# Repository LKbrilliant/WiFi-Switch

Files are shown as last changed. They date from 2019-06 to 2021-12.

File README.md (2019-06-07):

# WiFi-Switch 
📡 **WiFi-Switch** is a wall outlet adapter which can be controlled through the home wierless network. It can turn On/Off any device which plugs into it. This project is based on the ESP8266-01 module. Independent static-ip addresses can be use when deploying several switches around the house.

Schematics:
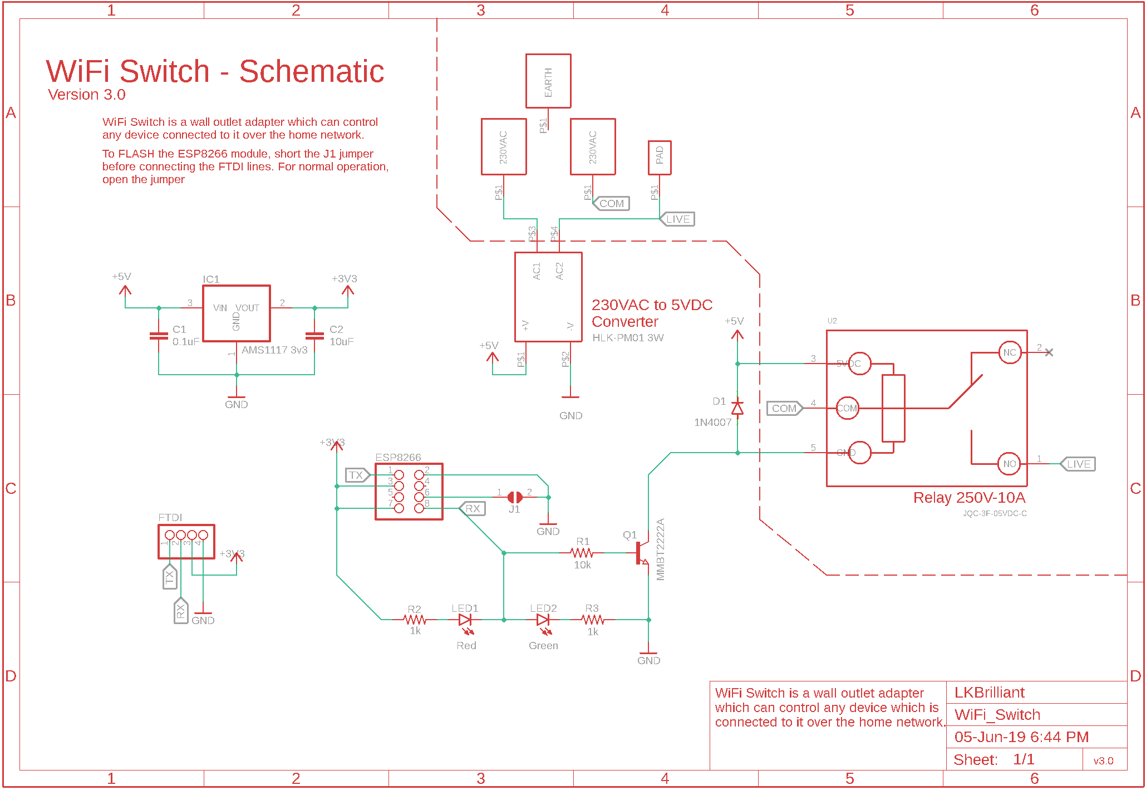
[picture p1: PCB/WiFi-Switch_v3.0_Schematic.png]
Schematic


PCB:
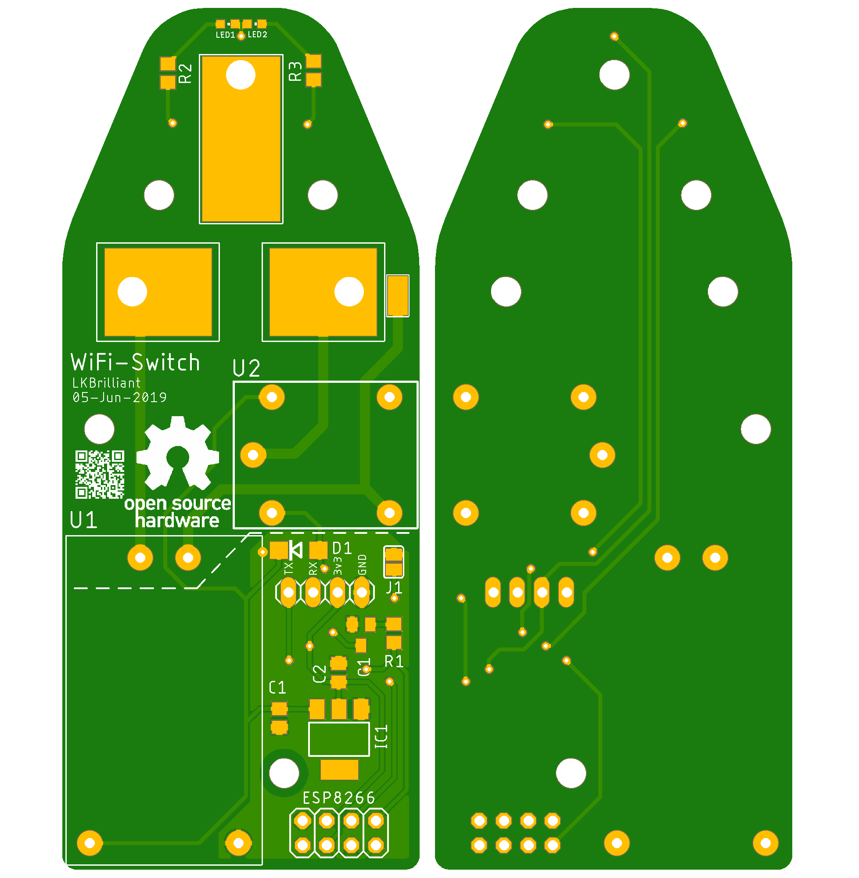
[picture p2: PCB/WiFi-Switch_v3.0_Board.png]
Board


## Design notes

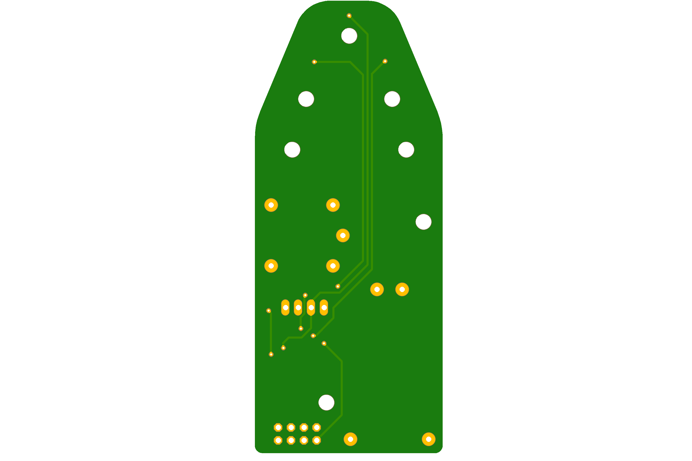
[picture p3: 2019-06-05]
PCB/WiFi-Switch_v3.0_Board_back.png

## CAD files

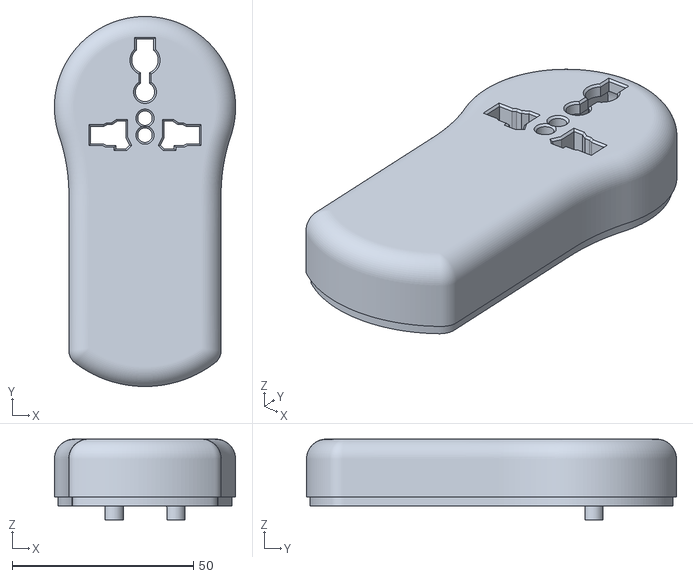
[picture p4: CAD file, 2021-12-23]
3D-models/Front.stl
50.0 x 102.1 x 22.3

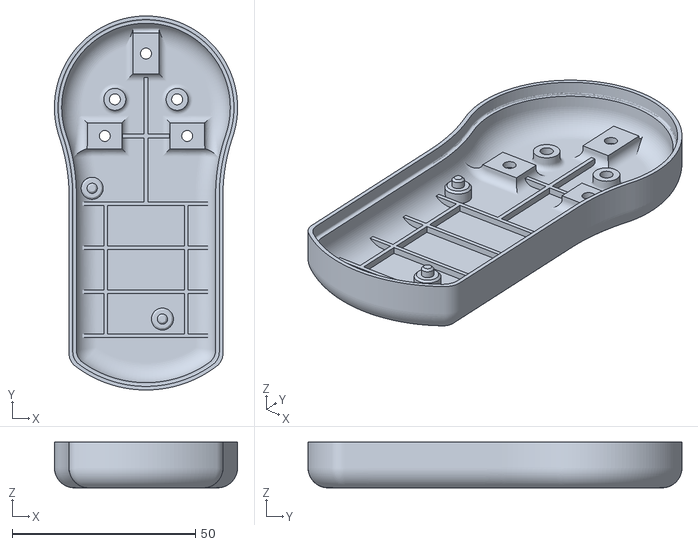
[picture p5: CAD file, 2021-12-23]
3D-models/Back.stl
50.0 x 102.1 x 12.5

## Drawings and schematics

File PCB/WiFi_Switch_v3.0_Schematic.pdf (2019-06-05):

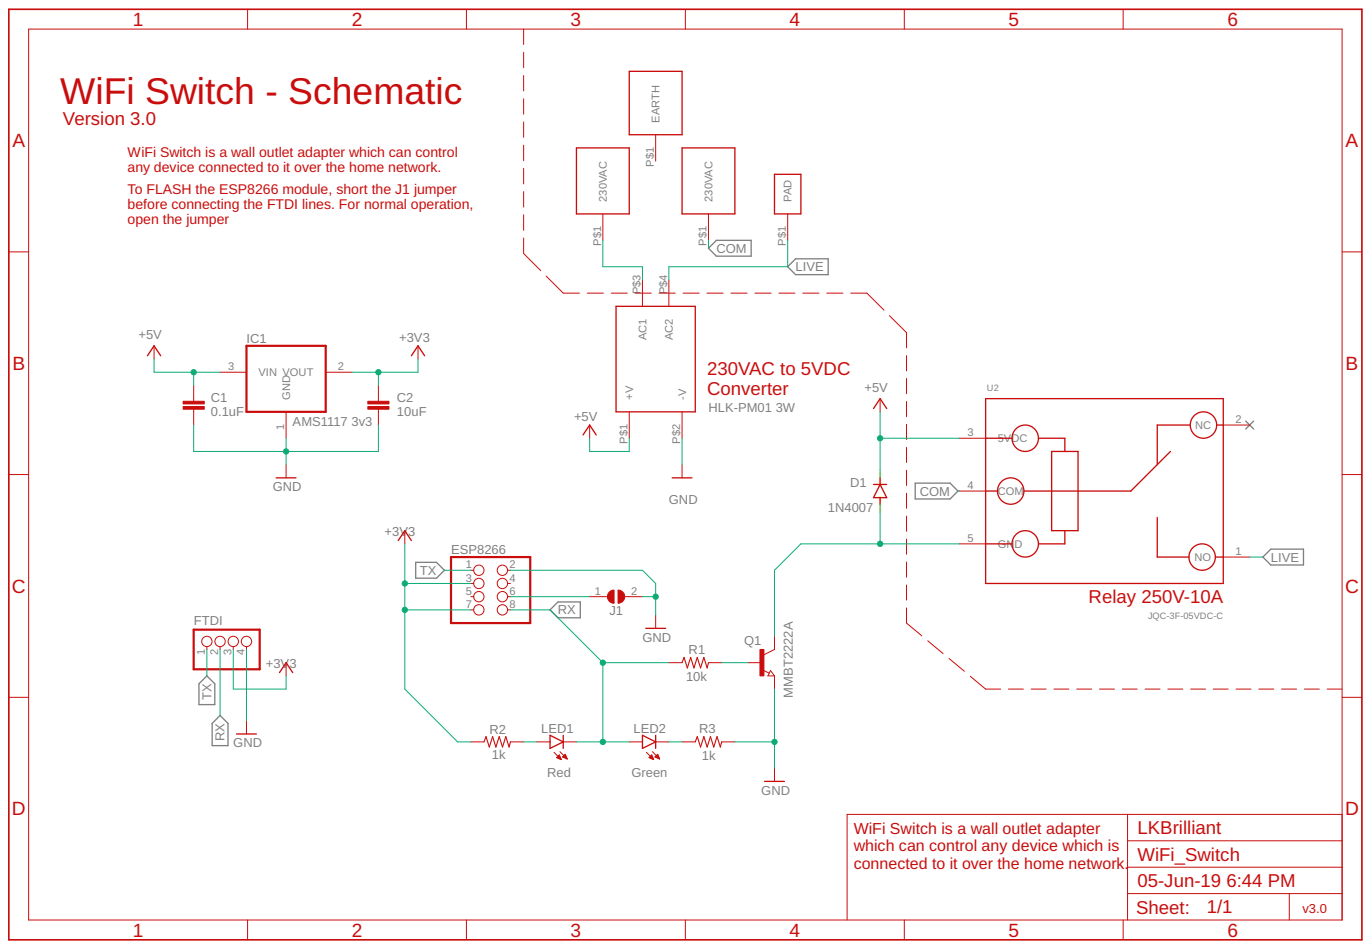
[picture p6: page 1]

WiFi Switch is a wall outlet adapter which can control any device connected to it over the home network. To FLASH the ESP8266 module, short the J1 jumper before connecting the FTDI lines. For normal operation, open the jumper

which can control any device which is
connected to it over the home network.

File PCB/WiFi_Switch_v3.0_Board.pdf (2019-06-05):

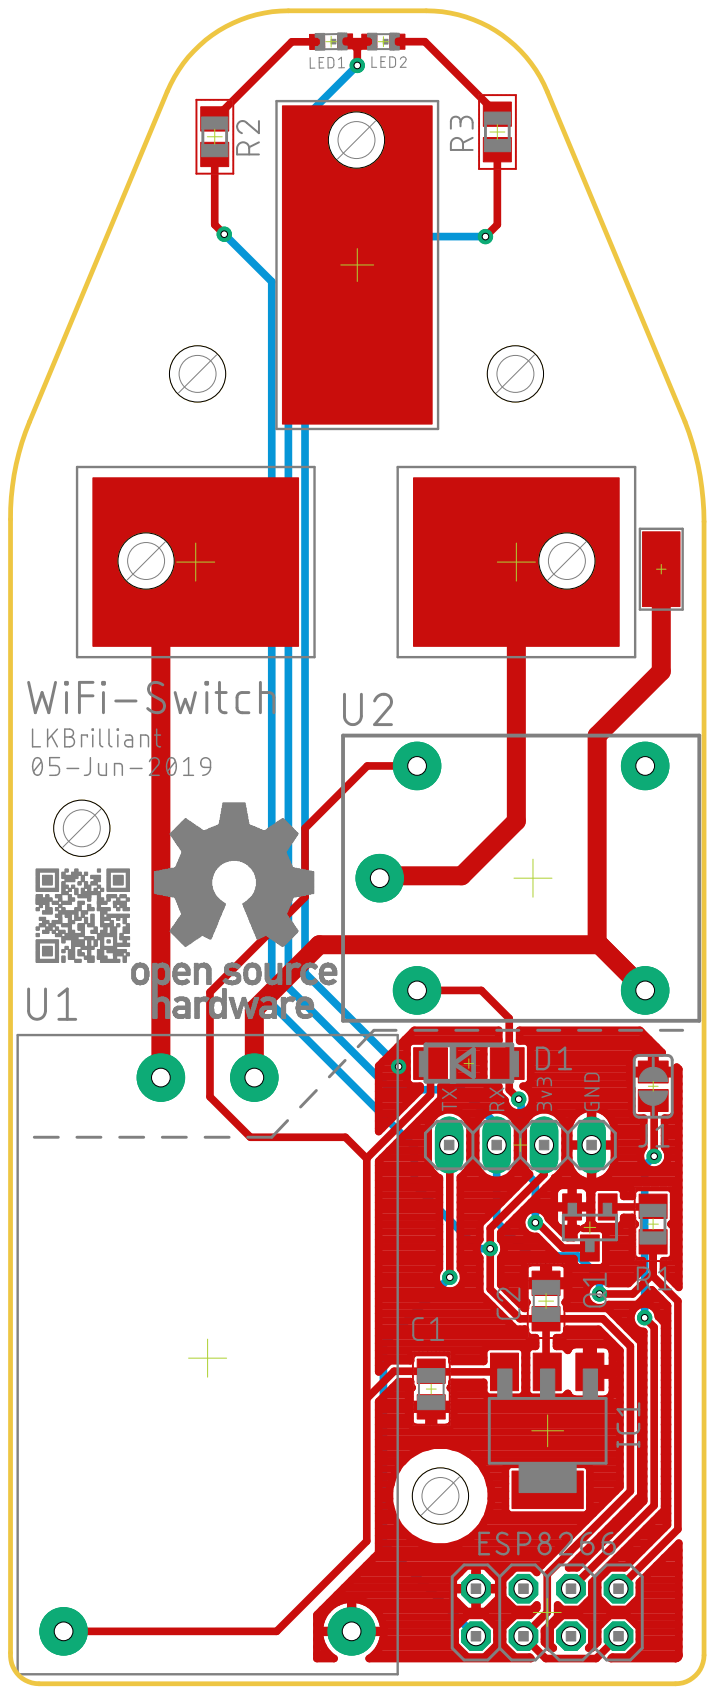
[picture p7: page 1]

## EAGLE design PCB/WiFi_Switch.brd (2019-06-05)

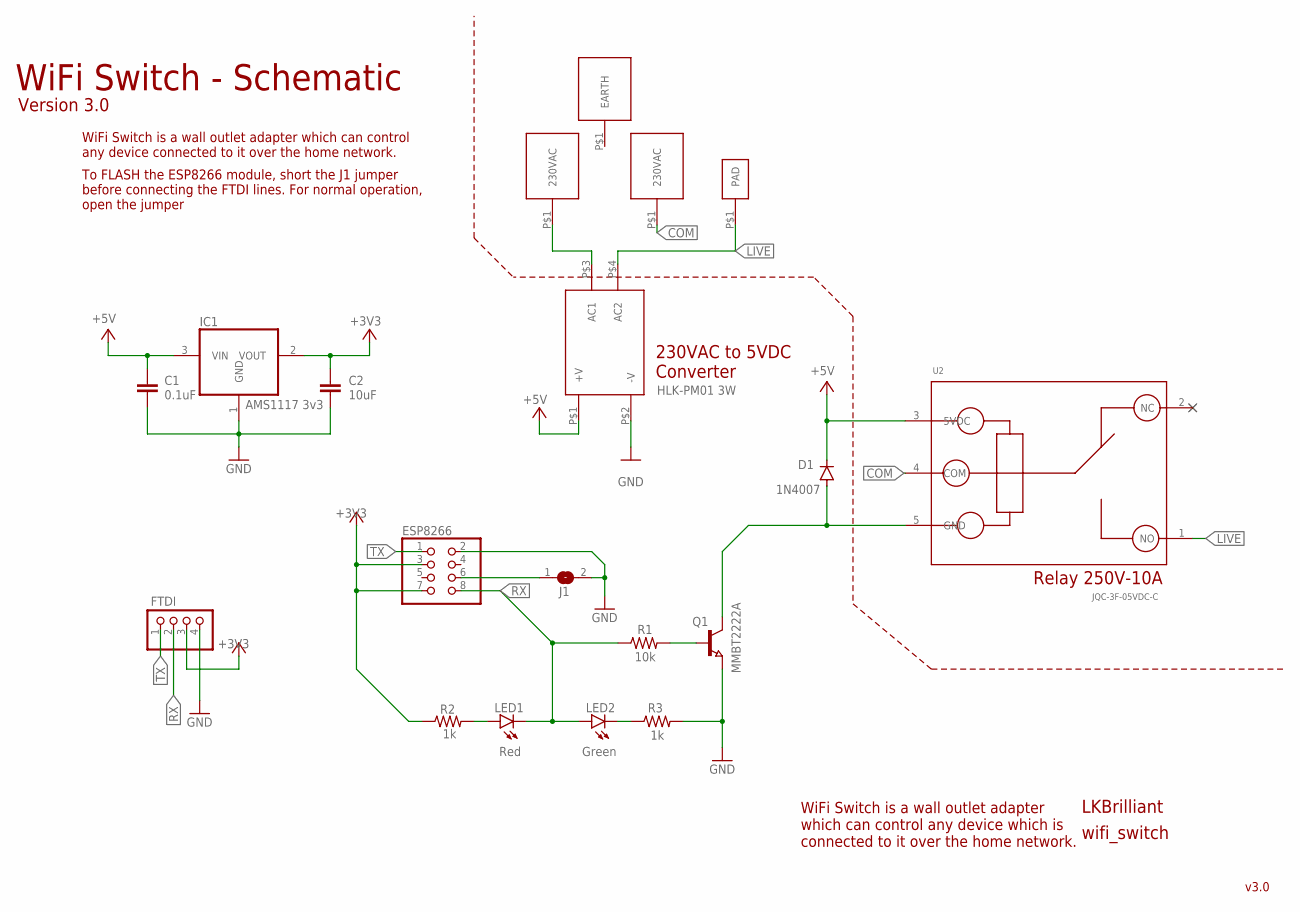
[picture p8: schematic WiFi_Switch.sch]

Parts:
C1: 0.1uF; C0805
C2: 10uF; C0805
D1: 1N4007; DO214AC
ESP8266: PINHD-2X4; 2X04
FTDI: PINHD-1X4; 1X04
IC1: AMS1117 3v3; SOT223
J1: SJ
L: 230VAC_PAD; 11X9_SMD_PAD
LED1: Red; CHIPLED_0603
LED2: Green; CHIPLED_0603
N: 230VAC_PAD; 11X9_SMD_PAD
Q1: MMBT2222A; SOT23
R1: 10k; R0805
R2, R3: 1k; R0805
U1: 230VAC/5VDC_CONVERTER; REG_BLOCK
U2: JQC-3F-05VDC-C; JQC-3F
U$4: EARTH_PAD; 17X8_PAD
U$5: EXT_PAD; 4X2_PAD

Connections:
+3V3: C2.1, ESP8266.3, ESP8266.7, FTDI.3, IC1.2 (VOUT), R2.1
+5V: C1.1, D1.C, IC1.3 (VIN), U1.P$1 (+V), U2.3 (5VDC)
COM: L.P$1, U2.4 (COM)
GND: C1.2, C2.2, ESP8266.2, FTDI.4, IC1.1 (GND), J1.2, Q1.2 (E), R3.2, U1.P$2 (-V)
LIVE: U1.P$4 (AC2), U2.1 (NO), U$5.P$1
unnamed: LED1.A, R2.2
unnamed: N.P$1, U1.P$3 (AC1)
unnamed: ESP8266.6, J1.1
unnamed: D1.A, Q1.3 (C), U2.5 (GND)
unnamed: LED2.C, R3.1
unnamed: Q1.1 (B), R1.2
RX: ESP8266.8, FTDI.2, LED1.C, LED2.A, R1.1
TX: ESP8266.1, FTDI.1

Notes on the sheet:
v3.0
LKBrilliant
WiFi Switch is a wall outlet adapter which can control any device which is connected to it over the home network.
230VAC to 5VDC Converter
HLK-PM01 3W
Relay 250V-10A
WiFi Switch - Schematic
Version 3.0
WiFi Switch is a wall outlet adapter which can control any device connected to it over the home network.
To FLASH the ESP8266 module, short the J1 jumper before connecting the FTDI lines. For normal operation, open the jumper

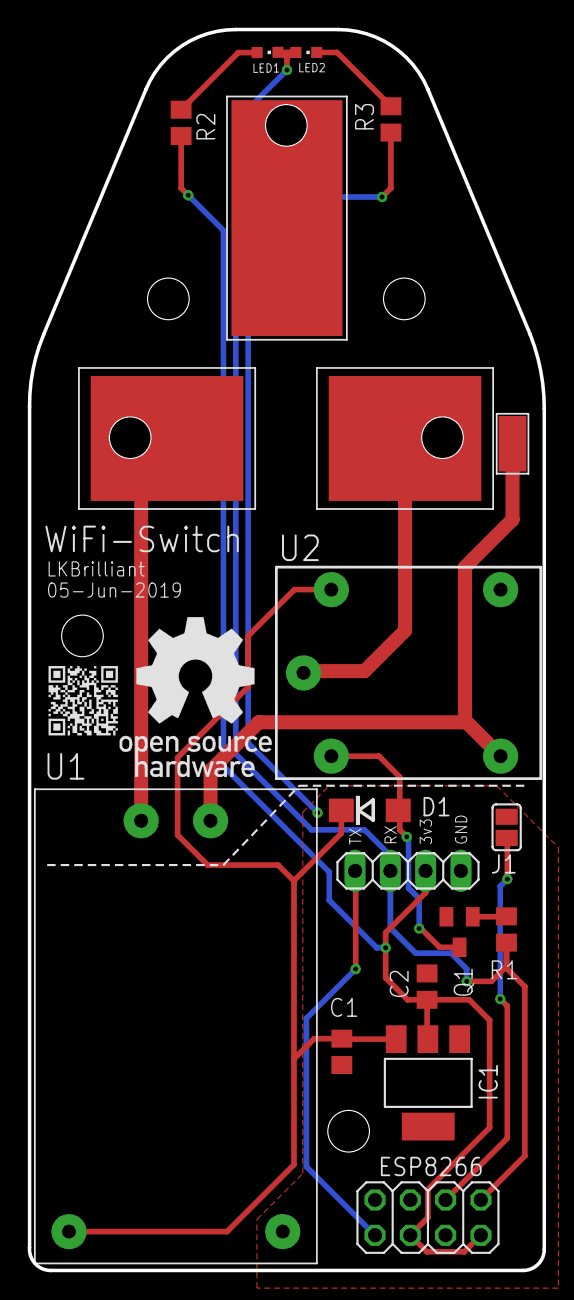
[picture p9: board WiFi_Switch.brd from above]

Board: 2 copper layers, 37.1 x 89.4 mm, 19 parts (0 on the bottom side), 13 nets.

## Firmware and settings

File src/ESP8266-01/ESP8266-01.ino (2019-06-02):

/*  
  Code by   :   Anuradha Gunawardhana
  date      :   02-Jun-2019
  version   :   1.0.020619

*/


#define relay 3   // relay is on GPIO 3 
#define led 1     //On board LED

#include <ESP8266WiFi.h>
#include <WiFiClient.h>
#include <ESP8266WebServer.h>

#include "index.h"                        // HTML webpage contents with javascripts

// Your WiFi credentials
const char* ssid = "YOUR_SSID";
const char* password = "YOUR_PASSWORD";

String current_relay_state = "0";  

ESP8266WebServer server(80);              //Server on port 80

IPAddress staticIP(192, 168, 1, 90);      // ESP static ip
IPAddress gateway(192, 168, 1, 1);        // IP Address of WiFi Router (Gateway)
IPAddress subnet(255, 255, 255, 0);       // Subnet mask
IPAddress dns(8, 8, 8, 8);                // DNS

void setup(){  
  pinMode(relay, OUTPUT);
  digitalWrite(relay, LOW);
  pinMode(led, OUTPUT);
  digitalWrite(led, HIGH);                         // On board LED Active LOW
  
  WiFi.begin(ssid, password);                     //Connect to your WiFi router
  WiFi.config(staticIP, gateway, subnet, dns);
  
  while (WiFi.status() != WL_CONNECTED) {         // Wait for connection
    delay(500);
  }
 
  server.on("/", handleRoot);                     //Which routine to handle at root location. This is display page
  server.on("/setRelay", relayHandle);
  server.on("/getRelayState", GetRelayStateHandle);
  server.begin();                                 //Start the server
}

void loop(){
  server.handleClient();                          //Handle client requests
}

void handleRoot() {
 String s = MAIN_page;              //Read HTML contents
 server.send(200, "text/html", s);  //Send web page
}

void relayHandle() {
 String relayState = "OFF";
 String t_state = server.arg("relayState"); //Refer  xhttp.open("GET", "setRelay?relayState="+state, true);

 if(t_state == "1"){
  digitalWrite(relay,HIGH);   //Relay ON
  digitalWrite(led,LOW);      // onboard LED Ative LOW
  relayState = "ON";          //Feedback parameter

  current_relay_state = "1";
 }
 else{
  digitalWrite(relay,LOW);    //Relay OFF
  digitalWrite(led,HIGH);     // onboard LED Ative LOW
  relayState = "OFF";         //Feedback parameter  

  current_relay_state="0";
 }
 
 server.send(200, "text/plane", relayState); //Send web page
}

void GetRelayStateHandle() {
 server.send(200, "text/plane", current_relay_state); //Send web page
}

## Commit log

2019-05-20 initial upload
    [WiFi_Switch.brd, WiFi_Switch.sch]
2019-05-20 upload PCB data
2019-05-22 changes for v2.1
    [WiFi_Switch.brd, WiFi_Switch.sch]
2019-05-22 Update for schematic v2.1
2019-05-30 Update for PCB v2.2
2019-05-30 update readme for PCB v2.2
2019-05-30 Schematic info update
2019-06-05 version 3.0 update
    [WiFi_Switch.brd, WiFi_Switch.sch]
2019-06-07 Add board image
2021-12-23 3D-models added
    [Back.stl, Front.stl]
